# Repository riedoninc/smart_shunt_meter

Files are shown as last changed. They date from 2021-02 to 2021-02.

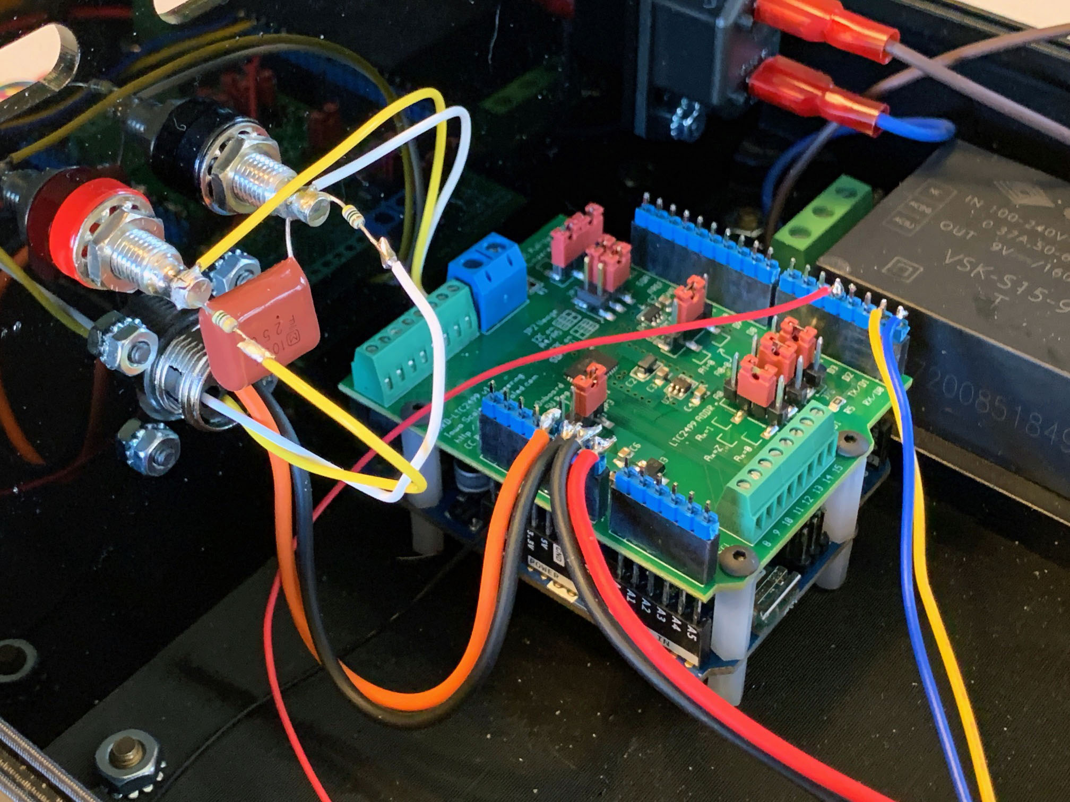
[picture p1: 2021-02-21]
Images/IMG_7710.JPG

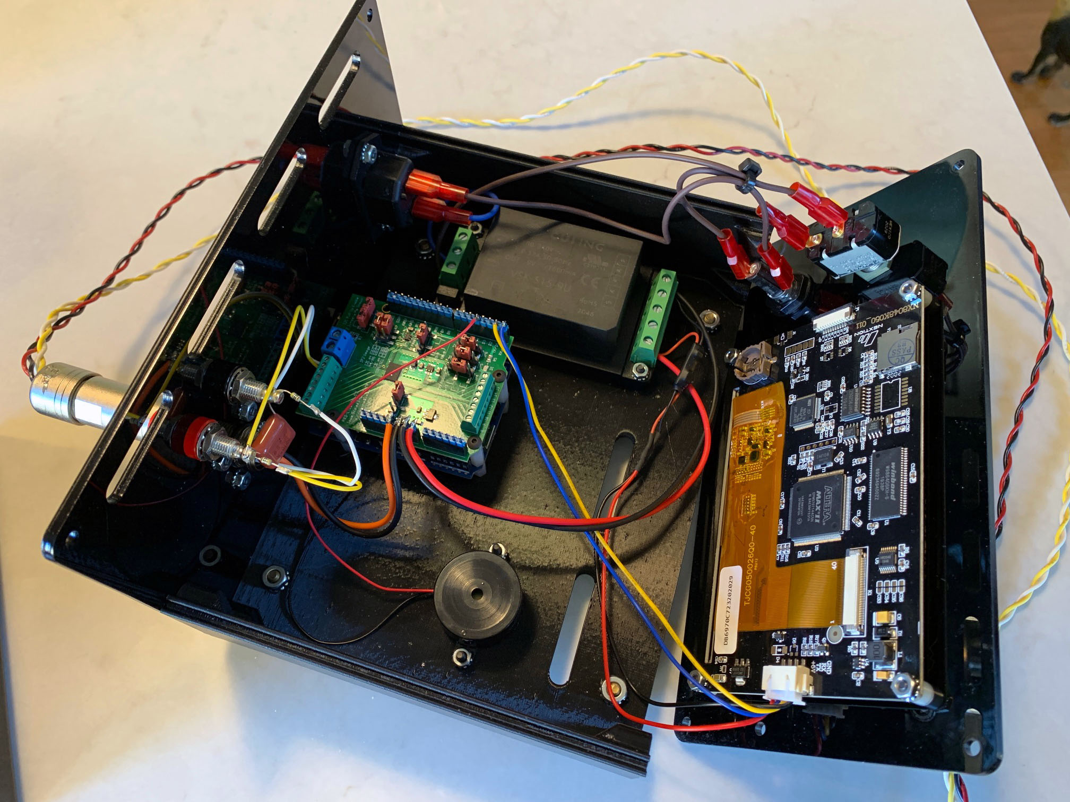
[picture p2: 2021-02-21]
Images/IMG_7709.JPG

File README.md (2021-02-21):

# Smart Shunt Meter

Precision Arduino based DC Current Meter with Touch Screen Interface

Uses an Arduino UNO WiFi Rev2, NX8048T050 Nextion display, Iowa Scaled ARD-LTC2499 ADC Shield, and a 
Riedon SSA series current sensor in either a 100, 250, 500, or 1000 amp version.

The 24bit ADC on the ARD-LTC2499 matched with the SSA sensor will give better than +/-0.1% accuracy.
The ARD-LTC249 is very low noise and can measure up to 8 differential pair signals to +/-2.048 VDC
at either 7.5 or 15 samples per second.

The Riedon SSA sensor is amplified and has reinfoced isolation up to 1500VDC (1000VAC). 
It is UL approved for both CAT II and CAT III uses.

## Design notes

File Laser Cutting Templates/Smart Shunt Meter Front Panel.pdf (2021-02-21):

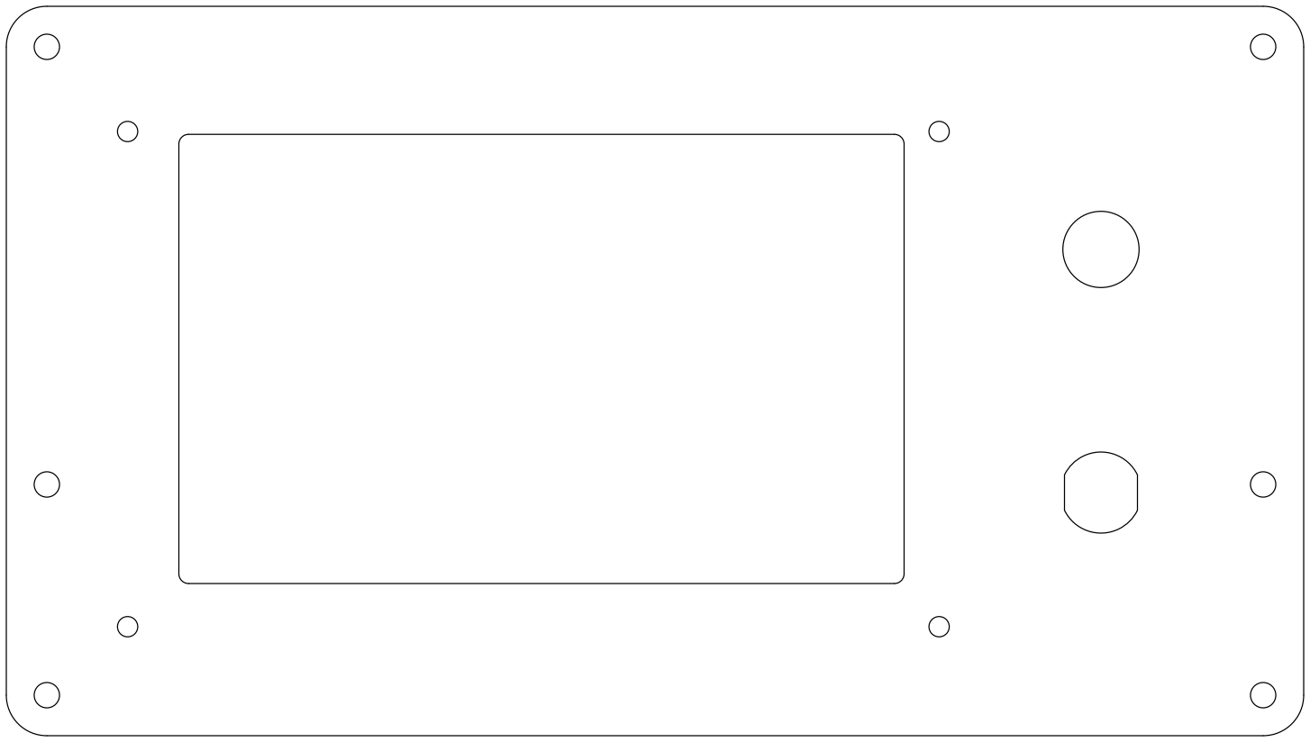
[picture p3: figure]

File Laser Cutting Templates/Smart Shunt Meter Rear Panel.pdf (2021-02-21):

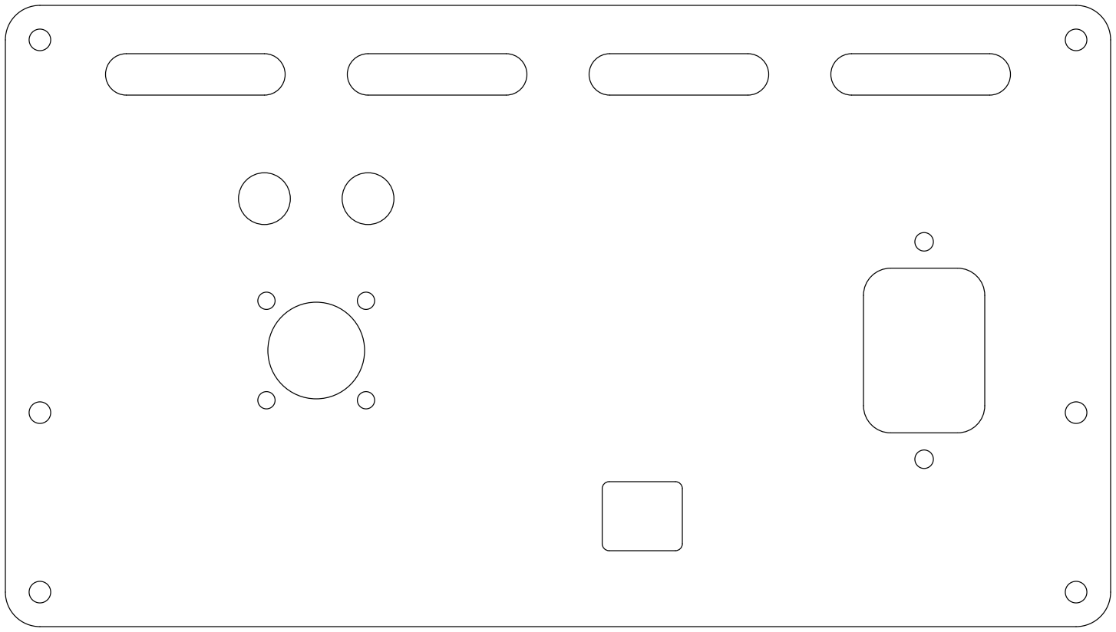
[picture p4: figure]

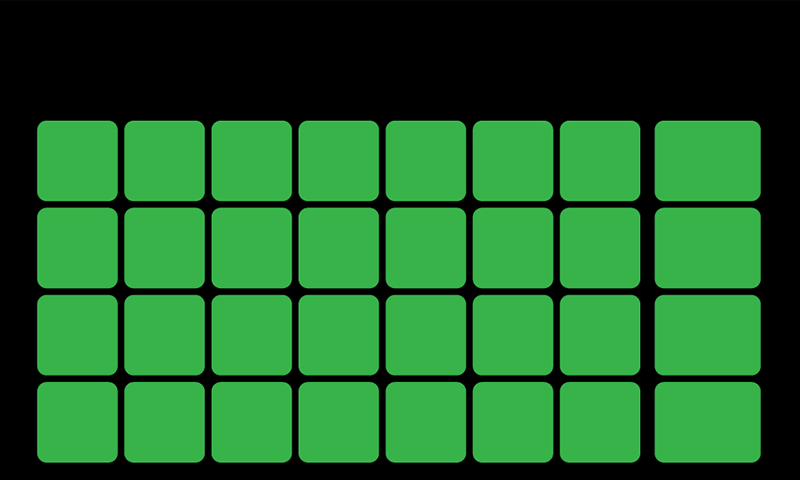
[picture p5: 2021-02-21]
Nextion Display/ASCII Data Entry Pressed.png

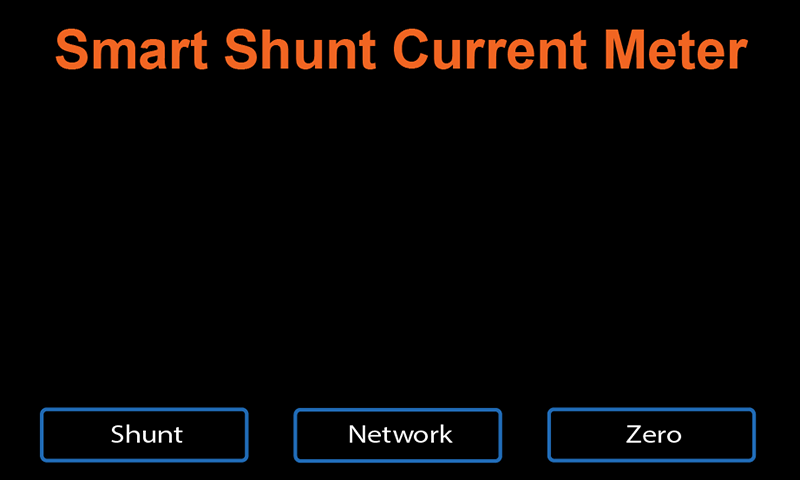
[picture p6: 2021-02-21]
Nextion Display/Home.png

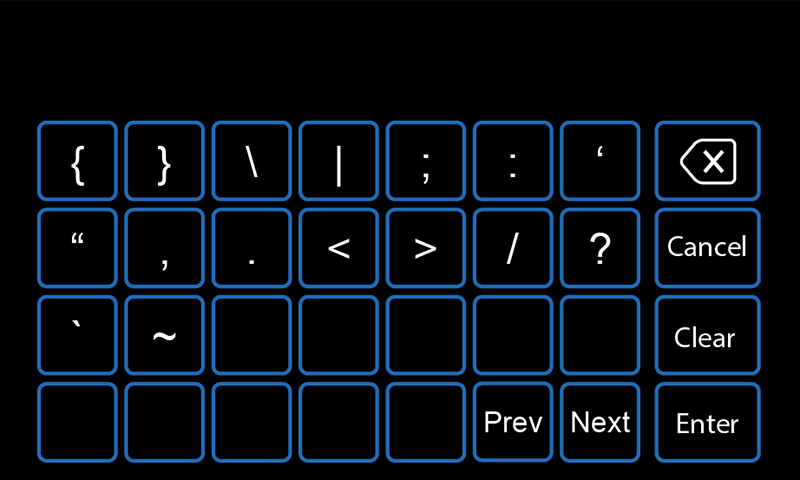
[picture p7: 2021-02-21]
Nextion Display/Symbols Data Entry.png

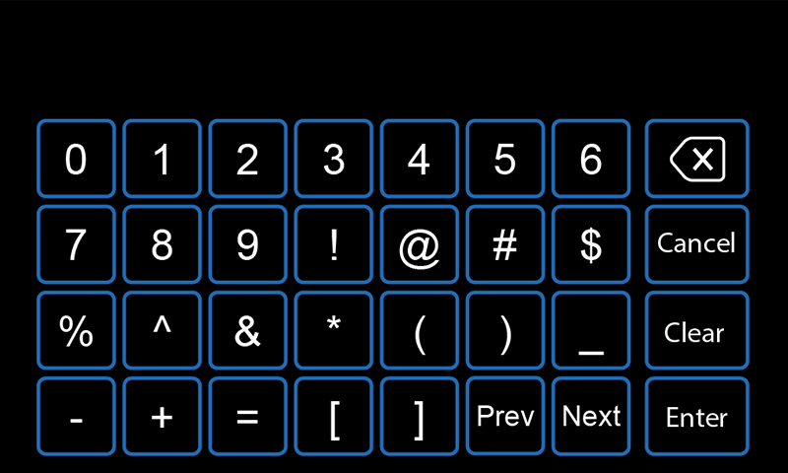
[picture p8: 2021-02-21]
Nextion Display/Numbers Data Entry.png

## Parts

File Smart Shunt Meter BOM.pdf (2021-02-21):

PART NUMBER | DESCRIPTION | QTY. | Link
Top Enclosure | 3D Print Enclosure | 1
Bottom Enclosure | 3D Print Enclosure | 1
Display Bezel | 3D Print Bezel | 1
Front Panel | Laser Cut Panel | 1
Rear Panel | Laser Cut Panel | 1
93365A132 | 6-32 Heat Insert | 12 | https://www.mcmaster.com/93365A132/
94639A704 | 3/16" Nylon Spacer | 4 | https://www.mcmaster.com/94639A704/
92745A374 | 4-40x3/8 Standoff | 3 | https://www.mcmaster.com/92745A374/
92319A874 | 4-40x5/8 Standoff | 3 | https://www.mcmaster.com/92319A874/
91255A107 | 4-40x5/16 Screw | 8 | https://www.mcmaster.com/91255A107/
91255A108 | 4-40x3/8 Screw | 6 | https://www.mcmaster.com/91255A108/
91255A112 | 4-40x5/8" Screw | 8 | https://www.mcmaster.com/91255A112/
91255A145 | 6-32x5/16" Screw | 12 | https://www.mcmaster.com/91255A112/
90675A005 | 4-40 KEPS Locknut | 16 | https://www.mcmaster.com/90675A005/
90675A009 | 8-32 KEPS Locknut | 4 | https://www.mcmaster.com/90675A009/
9423T11 | Toggle Switch Label | 1 | https://www.mcmaster.com/9423T11/
9541K2 | Rubber Bumper | 4 | https://www.mcmaster.com/9541K2/
Uno WiFi rev2 | Arduino Controller | 1 | https://www.amazon.com/Arduino-UNO-WiFi-REV2-ABX00021/dp/B07MK598QV/
NX8048T050 | 5in Nextion Display | 1 | https://www.itead.cc/nextion-nx8048t050.html
ARD-LTC2499 | 24 bit ADC Shield | 1 | https://www.iascaled.com/store/ARD-LTC2499
VSK-S15-9U-T | CUI 9VDC Power Supply | 1 | https://www.digikey.com/en/products/detail/cui-inc/VSK-S15-9U-T/3503692
Wolfwhoop PW-D | 5VDC Converter | 1 | https://www.amazon.com/Wolfwhoop-Converter-Step-Down-Regulator-Stabilizer/dp/B076P4C42B/
56965T12 | Miniature Buzzer | 1 | https://www.mcmaster.com/56965T12/
7343K712 | Toggle Switch | 1 | https://www.mcmaster.com/7343K711-7343K712/
7087K15 | Fuse Holder | 1 | https://www.mcmaster.com/7087K15/
7124K422 | Double Banana Jack | 1 | https://www.mcmaster.com/7124K41-7124K412/
1333N44 | IEC Receptacle | 1 | https://www.mcmaster.com/1333N44/
6168T76 | 4 Pin Connector | 1 | https://www.mcmaster.com/6168T76/
6168T16 | 4 Pin Plug | 1 | https://www.mcmaster.com/6168T16/
7085K39 | 3A Fuse | 1 | https://www.mcmaster.com/7085K39/
| 499 Ohm 1% resistor | 2
| 1uF Capacitor | 1
SSA-100 | Riedon Analog Smart Shunt | 1 | https://www.digikey.com/en/products/detail/riedon/SSA-100/12149327
SSA-CABLE-1M | Riedon SSA Cable | 1 | https://www.digikey.com/en/products/detail/riedon/SSA-CABLE-1M/12149322
SSA-BASE | Riedon SSA Mounting Base | 1 | https://www.digikey.com/en/products/detail/riedon/SSA-BASE/12149323 160Hz Low pass filter

# Smart Shunt Meter BOM

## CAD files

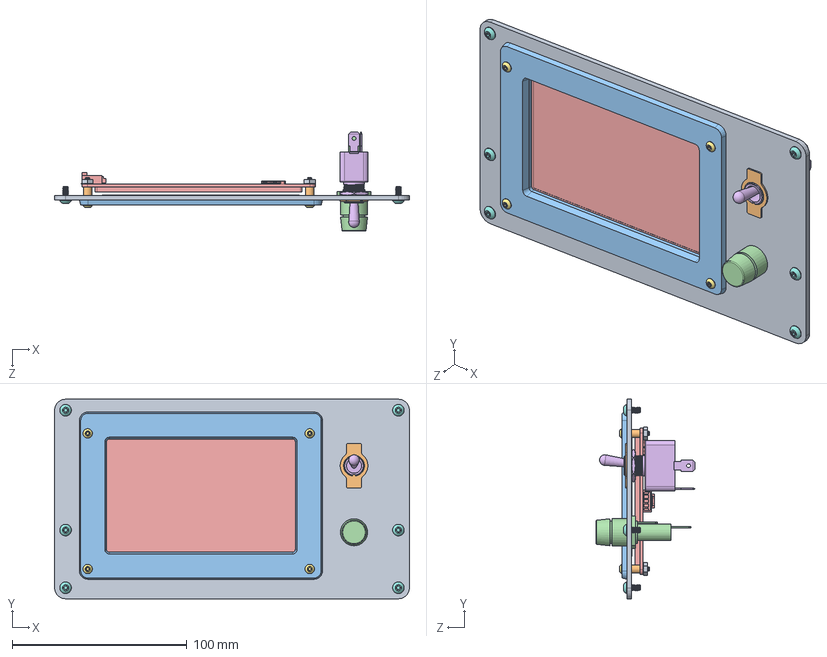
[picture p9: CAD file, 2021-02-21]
CAD/Solidworks/Front Panel Assy.SLDASM
203.2 x 114.3 x 56.9 mm
Smart Shunt Meter Front Panel
94639A704_OFF-WHITE NYLON UNTHREADED SPACER x 4
NEXTION NX8048T050 Bezel
Fuse Holder
DISPLAY NEXTION NX8048T050
7343K712_TOGGLE SWITCH
91255A112_BUTTON HEAD HEX DRIVE SCREW x 4
91255A145_ALLOY STEEL BUTTON-HEAD SOCKET CAP SCREW x 6
90675A005_ZINC-PLATED STEEL HEX NUT WITH TOOTH WASHER x 4
9423T110_LABELS FOR TOGGLE SWITCHES

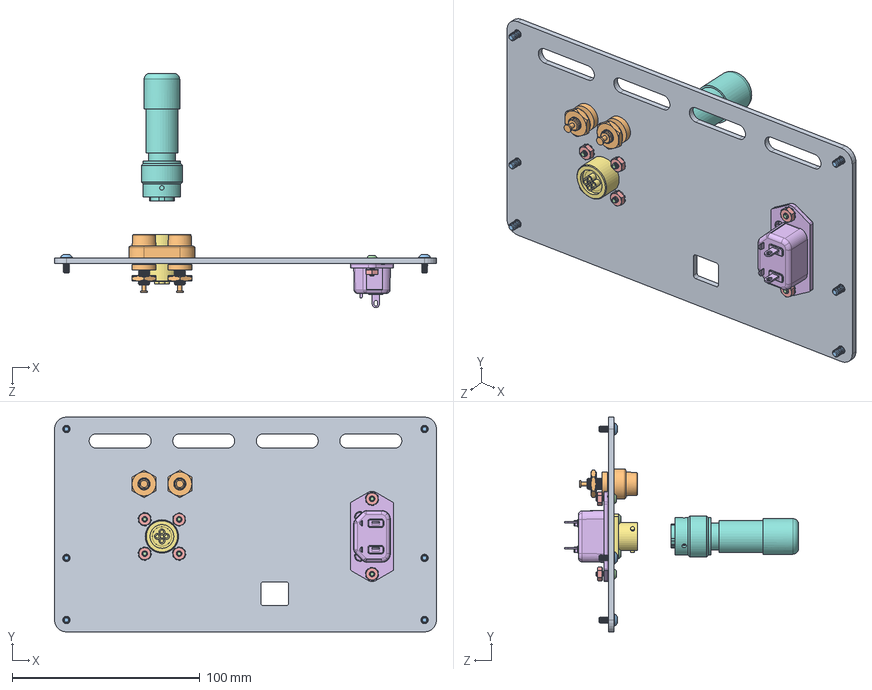
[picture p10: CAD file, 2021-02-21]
CAD/Solidworks/Rear Panel Assy.SLDASM
203.2 x 114.3 x 124.7 mm
Smart Shunt Meter Rear Panel
7124K422_PANEL-MNT BANANA JACK
91255A145_ALLOY STEEL BUTTON-HEAD SOCKET CAP SCREW x 6
91255A108_BUTTON HEAD HEX DRIVE SCREW x 6
90675A005_ZINC-PLATED STEEL HEX NUT WITH TOOTH WASHER x 6
1333N440_STRAIGHT-BLADE CONNECTOR
6168T760_QUICK-CONNECT CRIMP-STYLE CONNECTOR
6168T160_QUICK-CONNECT CRIMP-STYLE CONNECTOR

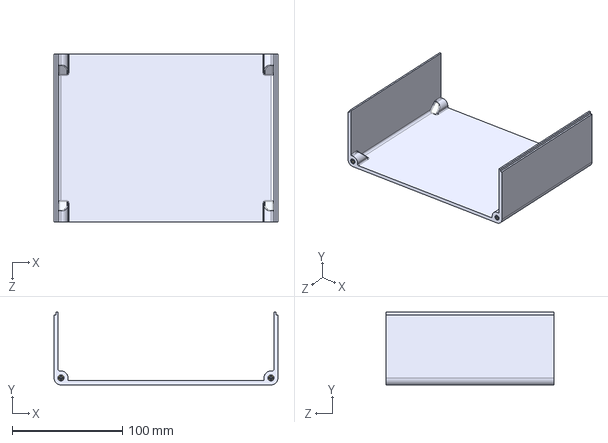
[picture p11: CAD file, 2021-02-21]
CAD/STEP/Top Panel Assy.step
203.2 x 66.0 x 152.4 mm
Smart Shunt Meter Top Enclosure
93365A132_HEAT-SET INSERTS FOR PLASTICS_93365A132 x 4

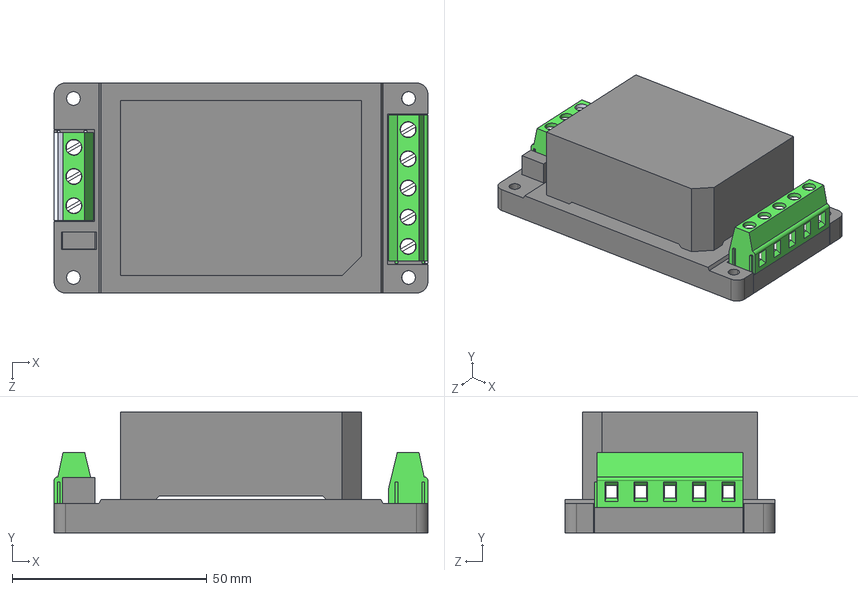
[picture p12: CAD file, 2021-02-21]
CAD/STEP/CUI_vsk-s15-9u-t.step
96.1 x 31.0 x 54.0 mm
CUI_vsk-t cover
CUI_vsk-t case
CUI_dg128-7.5_dg128-7.5 (3)
CUI_dg128-7.5_dg128-7.5 (5)
CUI_vsk-s15 series

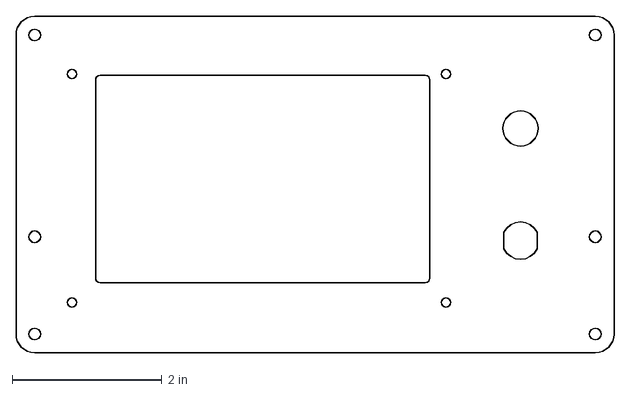
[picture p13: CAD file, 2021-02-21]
Laser Cutting Templates/Smart Shunt Meter Front Panel.DXF
8.00 x 4.50 in

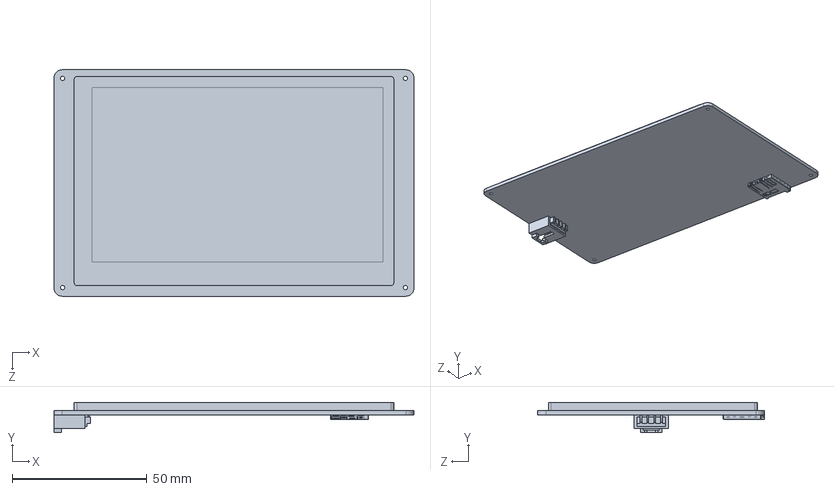
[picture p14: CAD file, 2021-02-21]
CAD/Solidworks/DISPLAY NEXTION NX8048T050.SLDPRT
133.5 x 11.2 x 84.0 mm

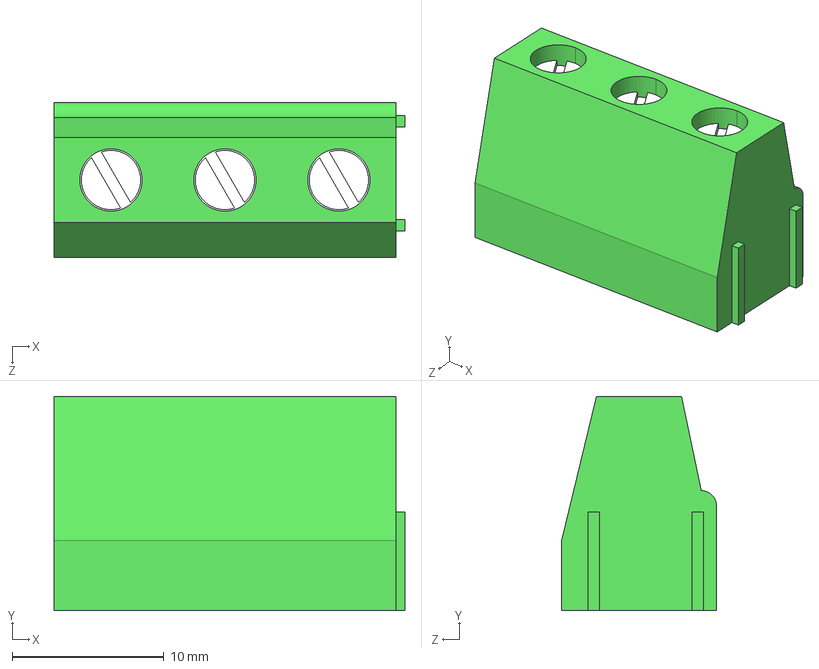
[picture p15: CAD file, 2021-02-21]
CAD/STEP/CUI_dg128-7.5_dg128-7.5 (3).step
23.1 x 14.1 x 10.2 mm

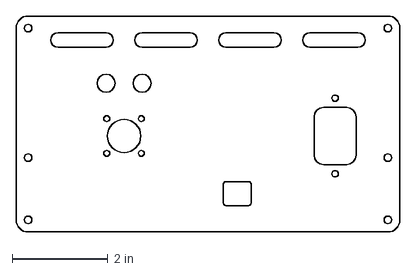
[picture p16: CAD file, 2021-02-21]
Laser Cutting Templates/Smart Shunt Meter Rear Panel.DXF
8.00 x 4.50 in

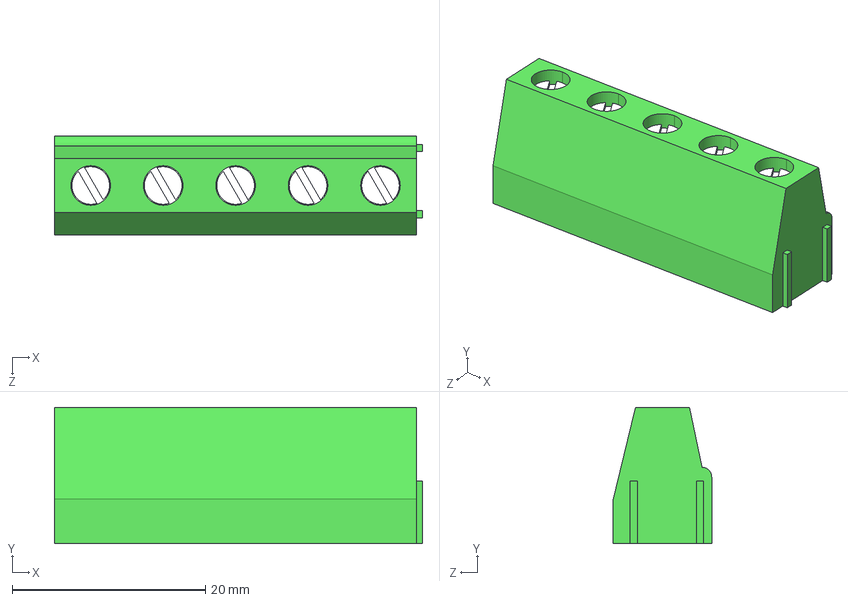
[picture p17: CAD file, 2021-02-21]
CAD/STEP/CUI_dg128-7.5_dg128-7.5 (5).step
38.1 x 14.1 x 10.2 mm

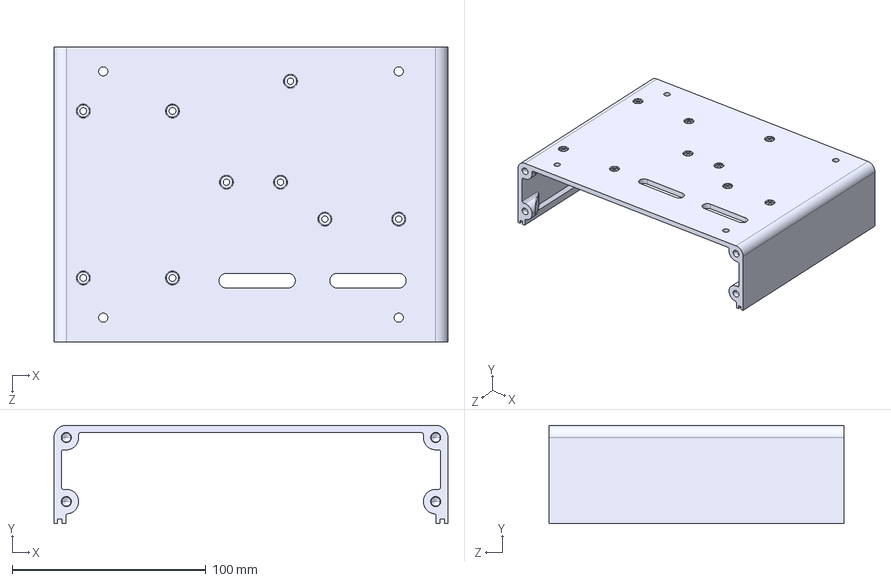
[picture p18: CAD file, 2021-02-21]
CAD/STEP/Smart Shunt Meter Bottom Enclosure.step
203.2 x 50.8 x 152.4 mm

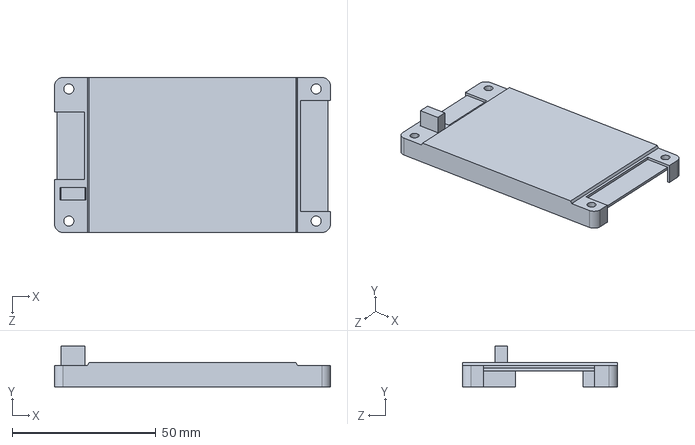
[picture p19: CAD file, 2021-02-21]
CAD/STEP/CUI_vsk-t case.step
96.1 x 14.2 x 54.0 mm

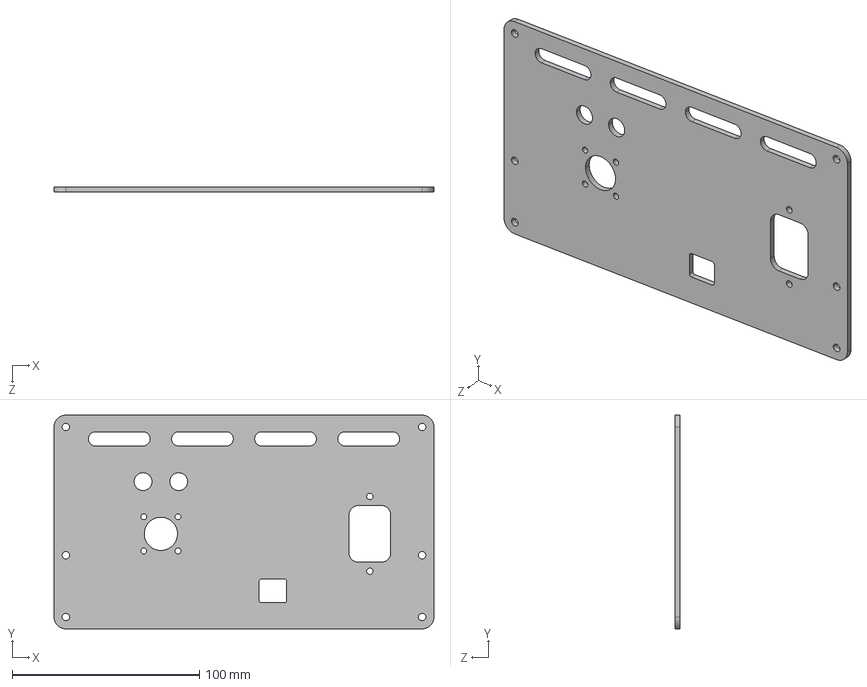
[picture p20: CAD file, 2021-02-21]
CAD/STEP/Smart Shunt Meter Rear Panel.step
203.2 x 114.3 x 2.79 mm

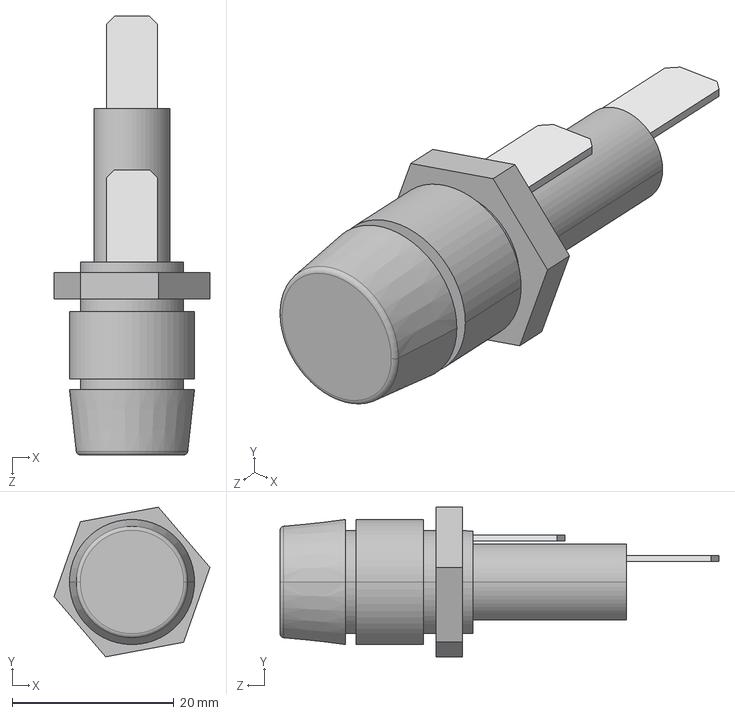
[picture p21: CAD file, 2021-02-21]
CAD/STEP/Fuse Holder.step
19.3 x 18.5 x 54.4 mm

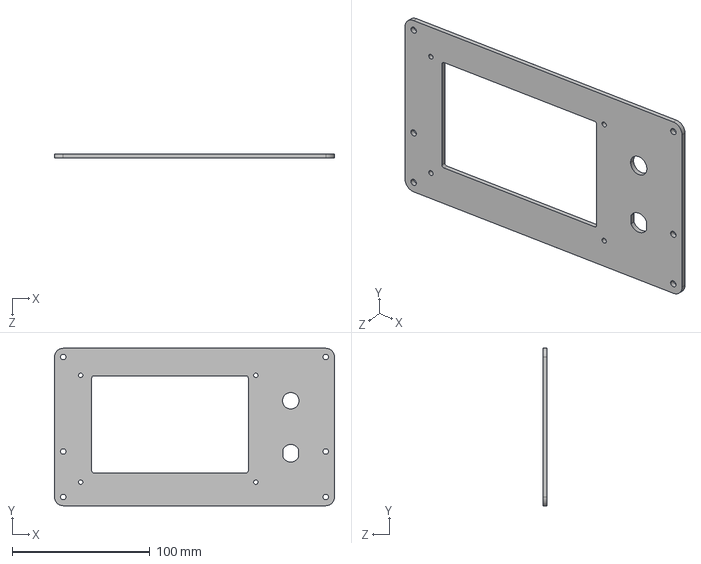
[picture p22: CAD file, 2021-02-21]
CAD/STEP/Smart Shunt Meter Front Panel.step
203.2 x 114.3 x 2.79 mm

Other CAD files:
CAD/STEP/Smart Shunt Meter Top Enclosure.step
CAD/STEP/CUI_vsk-t cover.step
CAD/STEP/CUI_vsk-s15 series.step
CAD/STEP/NEXTION NX8048T050 Bezel.step
CAD/STEP/1333N440_STRAIGHT-BLADE CONNECTOR.step
CAD/STEP/56965T12 Miniature Buzzer.step
CAD/STEP/6168T160_QUICK-CONNECT CRIMP-STYLE CONNECTOR.step
CAD/STEP/6168T760_QUICK-CONNECT CRIMP-STYLE CONNECTOR.step
CAD/STEP/7124K422_PANEL-MNT BANANA JACK.step
CAD/STEP/7343K712_TOGGLE SWITCH.step
CAD/STEP/90675A005_ZINC-PLATED STEEL HEX NUT WITH TOOTH WASHER.step
CAD/STEP/90675A009_ZINC-PLATED STEEL HEX NUT WITH TOOTH WASHER.step
CAD/STEP/91255A107_BUTTON HEAD HEX DRIVE SCREW.step
CAD/STEP/91255A108_BUTTON HEAD HEX DRIVE SCREW.step
CAD/STEP/91255A112_BUTTON HEAD HEX DRIVE SCREW.step
CAD/STEP/91255A145_ALLOY STEEL BUTTON-HEAD SOCKET CAP SCREW.step
CAD/STEP/92319A874_FEM THRDED HEX STANDOFF.step
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

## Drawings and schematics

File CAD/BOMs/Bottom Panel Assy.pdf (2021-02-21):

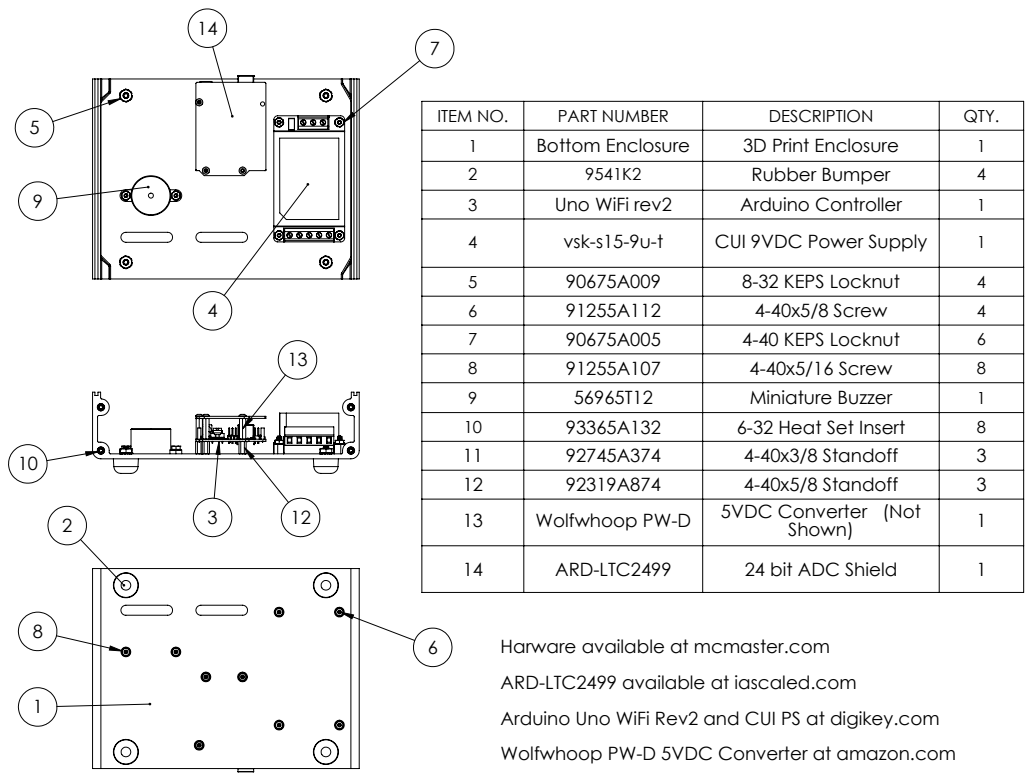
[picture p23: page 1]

ITEM NO. | PART NUMBER | DESCRIPTION | QTY.
1 | Bottom Enclosure | 3D Print Enclosure | 1
2 | 9541K2 | Rubber Bumper | 4
3 | Uno WiFi rev2 | Arduino Controller | 1
4 | vsk-s15-9u-t | CUI 9VDC Power Supply | 1
5 | 90675A009 | 8-32 KEPS Locknut | 4
6 | 91255A112 | 4-40x5/8 Screw | 4
7 | 90675A005 | 4-40 KEPS Locknut | 6
8 | 91255A107 | 4-40x5/16 Screw | 8
9 | 56965T12 | Miniature Buzzer | 1
10 | 93365A132 | 6-32 Heat Set Insert | 8
11 | 92745A374 | 4-40x3/8 Standoff | 3
12 | 92319A874 | 4-40x5/8 Standoff | 3
13 | Wolfwhoop PW-D | 5VDC Converter (Not Shown) | 1

14 | ARD-LTC2499 | 24 bit ADC Shield | 1

Harware available at mcmaster.com
ARD-LTC2499 available at iascaled.com
Arduino Uno WiFi Rev2 and CUI PS at digikey.com
Wolfwhoop PW-D 5VDC Converter at amazon.com

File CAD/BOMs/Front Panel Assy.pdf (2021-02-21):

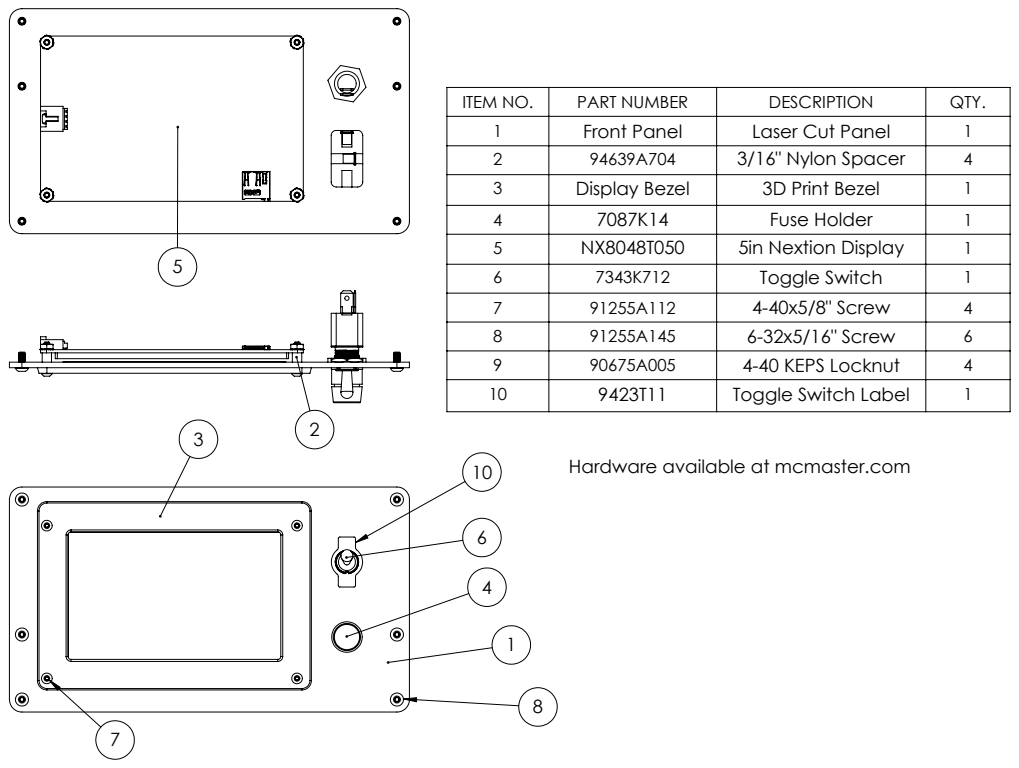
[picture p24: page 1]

ITEM NO. | PART NUMBER | DESCRIPTION | QTY.
1 | Front Panel | Laser Cut Panel | 1
2 | 94639A704 | 3/16" Nylon Spacer | 4
3 | Display Bezel | 3D Print Bezel | 1
4 | 7087K14 | Fuse Holder | 1
5 | NX8048T050 | 5in Nextion Display | 1
6 | 7343K712 | Toggle Switch | 1
7 | 91255A112 | 4-40x5/8" Screw | 4
8 | 91255A145 | 6-32x5/16" Screw | 6
9 | 90675A005 | 4-40 KEPS Locknut | 4
10 | 9423T11 | Toggle Switch Label | 1

Hardware available at mcmaster.com

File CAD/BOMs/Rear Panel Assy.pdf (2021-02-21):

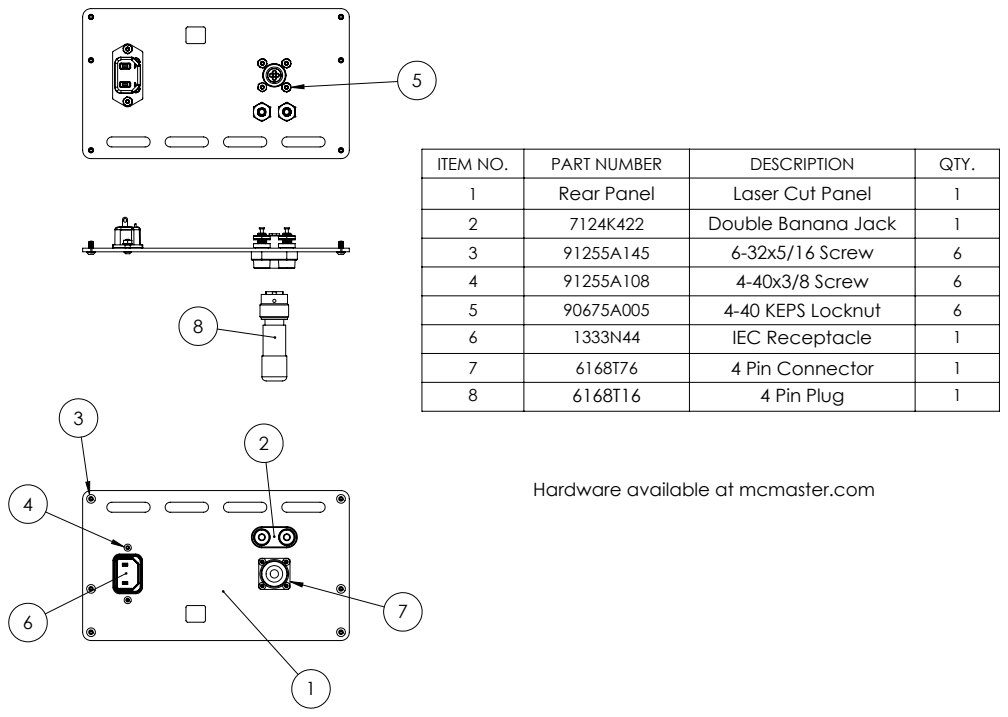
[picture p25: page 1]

ITEM NO. | PART NUMBER | DESCRIPTION | QTY.
1 | Rear Panel | Laser Cut Panel | 1
2 | 7124K422 | Double Banana Jack | 1
3 | 91255A145 | 6-32x5/16 Screw | 6
4 | 91255A108 | 4-40x3/8 Screw | 6
5 | 90675A005 | 4-40 KEPS Locknut | 6
6 | 1333N44 | IEC Receptacle | 1
7 | 6168T76 | 4 Pin Connector | 1
8 | 6168T16 | 4 Pin Plug | 1

Hardware available at mcmaster.com

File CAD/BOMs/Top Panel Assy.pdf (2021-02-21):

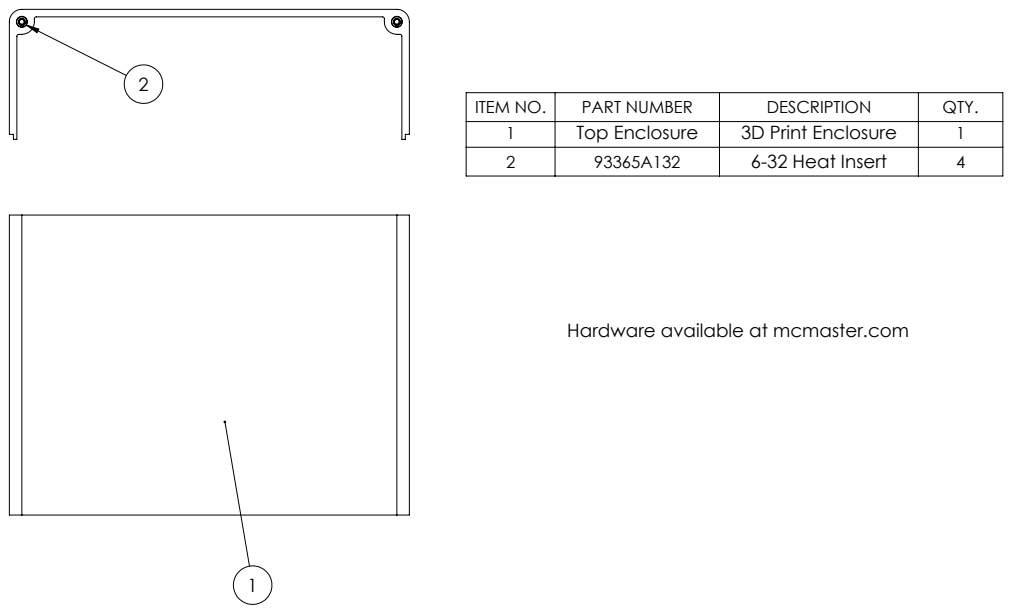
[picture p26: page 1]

ITEM NO. | PART NUMBER | DESCRIPTION | QTY.
1 | Top Enclosure | 3D Print Enclosure | 1
2 | 93365A132 | 6-32 Heat Insert | 4

Hardware available at mcmaster.com

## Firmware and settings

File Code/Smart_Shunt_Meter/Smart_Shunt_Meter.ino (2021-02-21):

/*************************************************************************
*  Title:    Smart Shunt Meter
*  Author:   Philip Ebbert
*  License:  GNU General Public License v3
*  
*  Program written for the Arduino UNO WiFi Rev2, NX8048T050 Nextion display, and ARD-LTC2499
*  Startup Guide for UNO Wifi Rev2:  https://www.arduino.cc/en/Guide/ArduinoUnoWiFiRev2
*  WiFiNINA library version 1.8.3, firmware version 1.4.3
*  Update WiFiNINA library and firmware here: https://github.com/arduino/WiFi101-FirmwareUpdater-Plugin
*  
*  Default is to connect to WiFi via DHCP
*  If you wish to use static IP address uncomment #define STATIC_IP and set ipaddr to desired value
*  
*  WiFi connection is automatically closed after sending a reading.
*  Send command READ? to IP address and port.
*  
*  Default Password 4444 for changing settings
*  
*  When setting up a new Arduino UNO WiFi Rev2, EEPROM is blank. Uncomment //#define write_EEPROM_initial and
*  upload sketch to write default values to EEPROM. Then comment out for normal operation.
*  
*  If using regular Arduino UNO, the display serial pins will nee to be ulplugged during programming as they 
*  are shared with the programming port. The UNO WiFi Rev2 has a separate serial port for programming.
*  
*  LICENSE:
*    Copyright (C) 2021 Philip Ebbert
*
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
*************************************************************************/

#include <Wire.h>
#include "Ard2499.h"
#include <SPI.h>
#include <WiFiNINA.h>
#include "EEPROM_Anything.h"            // Read & Write to EEPROM 

#define BEEPER   4                      // Beeper PIN
//#define STATIC_IP                     // Uncomment to set static IP address, otherwise DHCP
//#define write_EEPROM_initial          // Uncomment to write initial values to EEPROM

#ifdef STATIC_IP
  IPAddress ipaddr(192, 168, 8, 200);   // Set to Static IP desired
#endif

#define ENTER       0x0D                // Defines for Display Function Control Buttons
#define CANCEL      0x18
#define DELETE      0x08
#define CLEAR       0x1B
#define UP          0x11
#define DOWN        0x12
#define NEXT        0x13
#define PREV        0x14

#define ARRAYCOUNT(x)  (sizeof(x)/sizeof(x[0]))

char    ssid[32];                       // network SSID (name)
char    wifipass[32];                   // network password (use for WPA, or use as key for WEP)
String  strWifiPass;
String  strSSID;
int     keyIndex = 0;                   // your network key index number (needed only for WEP)

float   filteredAdc = 10;               // Set to 10 to force reset first pass
byte    keypress = 0;
long    adcVal;
float   Vadc;
float   VoltsPerAmp;                    // 0.0125 SSA-100, 0.005 SSA-250, 0.0025 SSA-500, 0.00125 SSA-1000
float   adcScalar;                      // Used to calibrate ADC
float   shuntOffset;                    // Used to zero reading 
float   filterWeight;                   // Used for exponential filtering of ADC, typically 0.05-0.20 (5-20%)
int     averageNumber;
byte    digitalFilter;
const char  *filtering_list[] = {"Mean Average", "Exponential"};

char    Data_Text[32];
char    Message[32];

long    wifiPort;
int     pass = 0, password = 4444;

Ard2499 ard2499board1; 

int status = WL_IDLE_STATUS;
int j = EEPROM_readAnything(30, wifiPort);         // Read Ethernet Port from EEPROM

WiFiServer server(wifiPort);

void setup() {

  //Initialize EEPROM Values

#ifdef write_EEPROM_initial

  VoltsPerAmp = 0.005;                             // 0.0125 SSA-100, 0.005 SSA-250, 0.0025 SSA-500, 0.00125 SSA-1000
  adcScalar = 1.00;                                // No scaling ADC value
  shuntOffset = 0.0;                               // Zero shunt offset
  filterWeight = 0.12;                             // 12% filterWeight on exponential filter 
  wifiPort = 5025;                                 // Listen on Port 5025
  digitalFilter = 0;                               // Mean Average mode
  averageNumber = 5;                               // Average 5 readings on Mean Average mode                             
    
  j = EEPROM_writeAnything(10, VoltsPerAmp);       // write VoltsPerAmp to EEPROM location 10, 4 bytes
  j = EEPROM_writeAnything(18, adcScalar);         // write adcScalar to EEPROM location 18, 4 bytes
  j = EEPROM_writeAnything(22, shuntOffset);       // write shuntOffset to EEPROM location 22, 4 bytes
  j = EEPROM_writeAnything(26, filterWeight);      // write filterWeight to EEPROM location 26, 4 bytes
  j = EEPROM_writeAnything(30, wifiPort);          // write VoltsPerAmp to EEPROM location 30, 4 bytes
  j = EEPROM_writeAnything(34, digitalFilter);     // write digitalFilter to EEPROM location 34, 1 byte
  j = EEPROM_writeAnything(38, averageNumber);     // write averageNumber to EEPROM location 34, 4 bytes

#endif
  
  j = EEPROM_readAnything(10, VoltsPerAmp);           // Read VoltsPerAmp from EEPROM
  j = EEPROM_readAnything(18, adcScalar);             // Read adcScalar from EEPROM
  j = EEPROM_readAnything(22, shuntOffset);           // Read shuntOffset from EEPROM
  j = EEPROM_readAnything(26, filterWeight);          // Read filterWeight from EEPROM
  j = EEPROM_readAnything(34, digitalFilter);         // Read digitalFilter from EEPROM
  j = EEPROM_readAnything(38, averageNumber);         // Read averageNumber from EEPROM

  for ( j = 0; j < 32; j++ ){                         // Read SSID from EEPROM
    ssid[j] = EEPROM.read( 100+j );
    if ( ssid[j] == '\0' ) break;
  }
  for ( j = 0; j < 32; j++ ){                         // Read WiFi Password from EEPROM
    wifipass[j] = EEPROM.read( 140+j );
    if ( wifipass[j] == '\0' ) break;
  }

  strWifiPass = wifipass;                             // Used to enter new WiFi SSID and Password
  strSSID = ssid;
  
  pinMode(BEEPER, OUTPUT);
  digitalWrite(BEEPER,LOW);

  // initialize serial communications
  Serial.begin(9600);                                 // start the serial monitor port
  Serial1.begin(115200);                              // Start display serial port at 115200 baud

  delay(200);
  DisplayWrite("dim=100");                            // Set brightness to 100%
  DisplayWrite("page 0");                             // Switch Display to Page 0
  delay(20);

  DisplayWrite("t0.txt=\"v1.0 \"");                   // Display Code Version
  DisplayWrite("t1.txt=\" \"");
  delay(1500);
  DisplayWrite("t0.txt=\"WiFi \"");

  Wire.begin();
  ard2499board1.begin(ARD2499_ADC_ADDR_ZZZ, ARD2499_EEP_ADDR_ZZ);
  ard2499board1.ltc2499ChangeConfiguration(LTC2499_CONFIG2_60_50HZ_REJ);
  ard2499board1.ltc2499ChangeChannel(LTC2499_CHAN_DIFF_1P_0N);

  // attempt to connect to WiFi network:
  Serial.print("Attempting to connect to SSID: ");
  Serial.println(ssid);
  
  // Connect to WPA/WPA2 network. Change this line if using open or WEP network:
  #ifdef STATIC_IP
    WiFi.config(ipaddr);
  #endif
  status = WiFi.begin(ssid, wifipass);

  // wait for connection:
  j = 0;
  do {
    delay(1500);
    if ( j++ > 5 ) break;
  } while ( WiFi.status() != WL_CONNECTED );
  
  if ( WiFi.status() == WL_CONNECTED ) {
    server.begin();
    printWifiStatus();
    Beep();
    DisplayWrite("t1.txt=\"ON  \"");
    Serial.println("Connected");
  }
  else {
    Beep();
    DisplayWrite("t1.txt=\"OFF  \"");
    Serial.println("WiFi not connected");
  }
  
  delay(2000);

  DisplayWrite("t0.txt=\"0.00000\"");
  DisplayWrite("t1.txt=\"0.00000\"");
}

void loop() {

  keypress = get_keypress ();                                 //Get keypress if available
  if ( keypress > 0 ) ProcessKeypress(keypress);

  ReadADC();

  UpdateDisplay(filteredAdc, filteredAdc/VoltsPerAmp);

  if ( WiFi.status() == WL_CONNECTED ) listenForWifiClients();

}

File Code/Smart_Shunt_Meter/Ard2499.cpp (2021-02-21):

/*************************************************************************
Title:    ARD-LTC2499 Driver Library
Authors:  Nathan D. Holmes <maverick@drgw.net>
File:     $Id: $
License:  GNU General Public License v3

LICENSE:
    Copyright (C) 2013 Nathan D. Holmes & Michael D. Petersen

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
*************************************************************************/

#include <stdlib.h>
#include <string.h>

#include "Ard2499.h"

byte Ard2499::ltc2499ChangeChannel(byte channel)
{
	return(ltc2499ChangeChannel(channel, true));
}

byte Ard2499::ltc2499ChangeChannel(byte channel, bool addStop)
{
	uint8_t config1=0, config2=0, blockingCountdown;	
	
	if (LTC2499_CHAN_TEMPERATURE == channel)
	{
		// The temperature channel is fake - it really has to change the config byte in the message
		current2499Channel = LTC2499_CHAN_TEMPERATURE;
		config1 = 0x80 | _BV(LTC2499_CONFIG1_ENABLE);
		config2 = _BV(LTC2499_CONFIG2_ENABLE2) | _BV(LTC2499_CONFIG2_IM) | (LTC2499_CONFIG2_CONFBITS & current2499Config);
	}
	else
	{
		current2499Channel = LTC2499_CONFIG1_CHANBITS & channel;
		config1 = 0x80 | _BV(LTC2499_CONFIG1_ENABLE) | (0x1F & current2499Channel);
		config2 = _BV(LTC2499_CONFIG2_ENABLE2) | (LTC2499_CONFIG2_CONFBITS & current2499Config);
	}

	// If there's no ltc2499 address, error out
	if(0 == i2cAddr_ltc2499)
		return(ARD2499_LTC2499_ERR);

	// Block in 5ms increments for up to 200ms.  Given the conversion rate 
	// should be greater than 7.5sps, 200ms is more than we should ever have to
	// wait.

	blockingCountdown = 40;
	while(blockingCountdown--)
	{
		this->WireInterface->beginTransmission(i2cAddr_ltc2499);
		this->WireInterface->write(config1);
		this->WireInterface->write(config2);
		if (0 != this->WireInterface->endTransmission(addStop))
		{
			if (0 == blockingCountdown)
				return(ARD2499_LTC2499_ERR);
			delay(5);
		}	
		else
			break;
	}

	return(ARD2499_SUCCESS);
}

byte Ard2499::ltc2499ChangeConfiguration(byte config)
{
	current2499Config = LTC2499_CONFIG2_CONFBITS & config;
	return(ltc2499ChangeChannel(current2499Channel));
}

long Ard2499::ltc2499Read()
{
	unsigned long rawValue = ltc2499ReadRaw();
	
	if (LTC2499_RAW_READ_ERROR == rawValue)
		return(LTC2499_READ_ERROR);

	uint8_t upperByte = 0xFF & (rawValue>>24);
	switch(upperByte)
	{
		case 0xC0:
			return(LTC2499_OVERRANGE_POSITIVE);
		case 0x3F:
			return(LTC2499_OVERRANGE_NEGATIVE);
	}
	rawValue = (rawValue & 0x7FFFFFFF)>>6; // Get rid of the sub-LSBs

	if (0x01000000 & rawValue)
		rawValue |= 0xFF000000;
	return((long)rawValue);

}

float Ard2499::ltc2499ReadVoltage()
{
	long value = ltc2499Read();
	
	if (LTC2499_OVERRANGE_POSITIVE == value)
		return(INFINITY);
	if (LTC2499_OVERRANGE_NEGATIVE == value)
		return(-1*INFINITY);

	return((value / 16777216.0) * (referenceMillivolts / 2000.0));
}

float Ard2499::ltc2499ReadVoltageAndChangeChannel(byte nextChannel)
{
	long value = ltc2499ReadAndChangeChannel(nextChannel);
	
	if (LTC2499_OVERRANGE_POSITIVE == value)
		return(INFINITY);
	if (LTC2499_OVERRANGE_NEGATIVE == value)
		return(-1*INFINITY);

	return((value / 16777216.0) * (referenceMillivolts / 2000.0));
}

long Ard2499::ltc2499ReadAndChangeChannel(byte nextChannel)
{
	if (ARD2499_SUCCESS != ltc2499ChangeChannel(nextChannel, false))
	{
		// Run another transmission through just to send out a stop bit
		this->WireInterface->beginTransmission(i2cAddr_ltc2499);
		this->WireInterface->endTransmission((uint8_t)true);
		return(LTC2499_READ_ERROR);
	}
	// Otherwise, we've succeeded and are sitting on a restart condition
	return(ltc2499Read());
}

unsigned long Ard2499::ltc2499ReadRaw()
{
	unsigned long retval=0;
	uint8_t blockingCountdown=40;

	if (0 == i2cAddr_ltc2499)
		return(0);

	// Block in 5ms increments for up to 200ms.  Given the conversion rate 
	// should be greater than 7.5sps, 200ms is more than we should ever have to
	// wait.
	while(blockingCountdown--)
	{
		this->WireInterface->requestFrom((uint8_t)i2cAddr_ltc2499, (uint8_t)4, (uint8_t)true);
		// Error occurred, we don't have as many bytes as expected
		if (this->WireInterface->available() < 4)
		{
			if (0 == blockingCountdown)
				return(LTC2499_RAW_READ_ERROR);
			delay(5);
		}	
		else
			break;
	}

	retval |= this->WireInterface->read();
	retval <<= 8;
	retval |= this->WireInterface->read();
	retval <<= 8;
	retval |= this->WireInterface->read();
	retval <<= 8;
	retval |= this->WireInterface->read();

	return(retval);
}

unsigned long Ard2499::ltc2499ReadRawAndChangeChannel(byte nextChannel)
{
	if (ARD2499_SUCCESS != ltc2499ChangeChannel(nextChannel, false))
	{
		// Run another transmission through just to send out a stop bit
		this->WireInterface->beginTransmission(i2cAddr_ltc2499);
		this->WireInterface->endTransmission((uint8_t)true);
		return(LTC2499_RAW_READ_ERROR);
	}
	// Otherwise, we've succeeded and are sitting on a restart condition
	return(ltc2499ReadRaw());
}

float Ard2499::ltc2499ReadTemperature(byte temperatureUnits)
{
	unsigned int tempDK = ltc2499ReadTemperatureDeciK();
	float tempK = (float)tempDK/10.0;
	switch(temperatureUnits)
	{
		case ARD2499_TEMP_K:
			return(tempK);
		case ARD2499_TEMP_C:
			return(tempK - 273.15);
		case ARD2499_TEMP_F:
			return(((tempK - 273.15) * 9.0)  / 5.0 + 32.0);
	}
	return(0);
}

unsigned int Ard2499::ltc2499ReadTemperatureDeciK()
{
	unsigned long readVal = 0;
	unsigned long tempDK = 0;
	
	// If we're currently not set for the temperature channel, switch us over
	// If we are currently set for the temp channel, then that write will have
	// triggered a conversion, and ltc2499ReadRaw will block until it's done
	if(LTC2499_CHAN_TEMPERATURE != current2499Channel)
		ltc2499ChangeChannel(LTC2499_CHAN_TEMPERATURE, true);
	
	readVal = ltc2499ReadRaw();
	
	if (LTC2499_RAW_READ_ERROR == readVal)
		return(0);

	// Throw away the sub-LSBs
	readVal >>= 6;

	tempDK = (0x00FFFFFF & readVal);
	// Divide by 2 for FS = 1/2 VREF
	// Divide by 1570 (eqn from 2499 datasheet)
	// Divide by 100 to convert millivolts to decivolts
	tempDK = (tempDK * (unsigned long)referenceMillivolts) / 314000;

	// tempDK is now the temperature in deci-kelvin
	return(tempDK);
}

Ard2499::Ard2499()
{
	init_status = ARD2499_LTC2499_ERR | ARD2499_EEPROM_ERR;
	i2cAddr_ltc2499 = 0;
	i2cAddr_eeprom = 0;
	current2499Config = 0;
	current2499Channel = 0;

#ifdef ARDUINO_SAM_DUE
	WireInterface = &Wire1;
#else 
	WireInterface = &Wire;
#endif

	strcpy(eui48, "Unknown");
}

Ard2499::Ard2499(TwoWire& wire)
{
	Ard2499();
	this->WireInterface = &wire;
}


const char* Ard2499::eui48Get()
{
	return(eui48);
}
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
